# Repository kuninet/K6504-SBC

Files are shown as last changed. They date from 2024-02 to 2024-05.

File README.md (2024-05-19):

# K6504-SBC

## 概要

* R6504 CPU(6502 CPUの仲間)を使ったシングルボードコンピューターです。
  * アドレシングできる範囲は8kBです。
  * RAM4kB、ROM3kB UniversanMonitorを動かすのが目標です

## 回路図

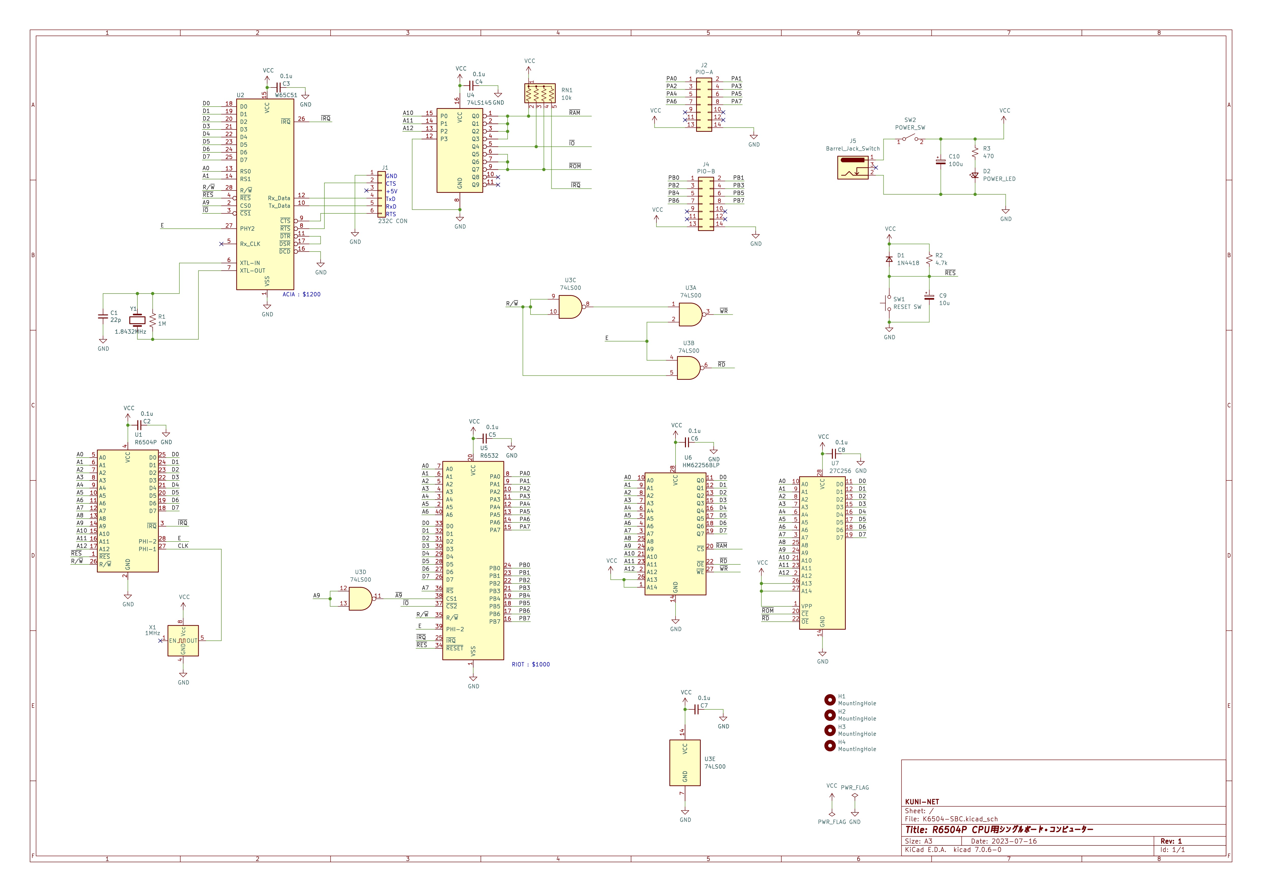
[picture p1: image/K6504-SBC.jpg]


## 基板製造データ

* プリント基板を製造するには、KiCAD/PCB フォルダに入っているzipファイルをお使いください。

## 部品表

[KiCAD/K6504-SBC.csv](KiCAD/K6504-SBC.csv)

## 注意点

* シリアルIC(6551)、RAM/IO/TIMER IC(6532)の割り込み信号線は、基板裏のソルダージャンパーをはんだで短絡すると有効になります。

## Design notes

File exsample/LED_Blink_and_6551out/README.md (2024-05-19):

# LEDチカチカ & W65C51経由シリアルへの出力テスト

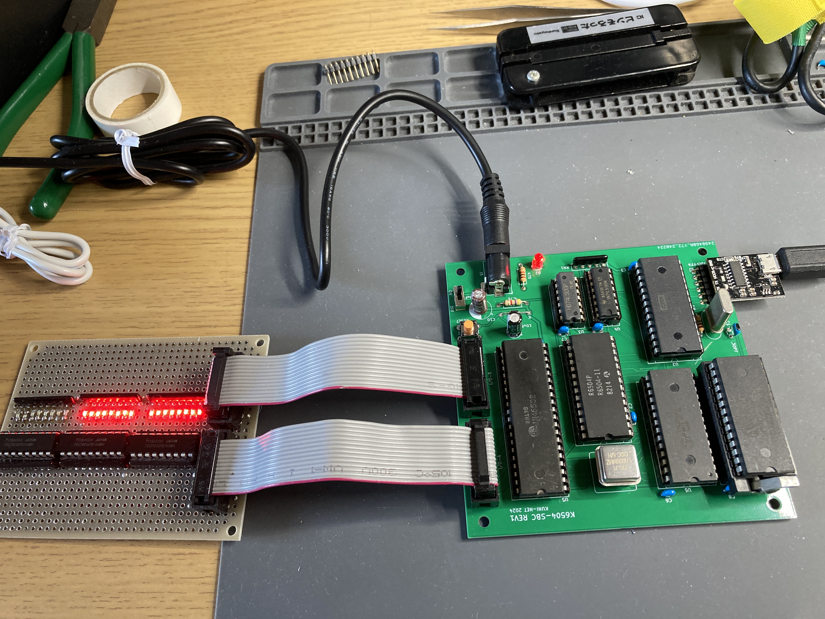
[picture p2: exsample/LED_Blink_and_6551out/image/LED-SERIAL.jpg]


## 概要

* K6504-SBCの単純な動作確認として使える、LEDチカチカ(1～255カウントアップ)と シリアルへの出力プログラムです。
  * ★ROMに焼いて使用するものです。

## アセンブリと使い方

### ソースからのビルド方法

* Linux等のUNIX環境で [The Macroassembler AS](http://john.ccac.rwth-aachen.de:8000/as/)が動くようにしてください。アセンブリに必要なツールです。
  * 基本的に `Downloadページ` > `latest build`のCソースを持ってきて、gccでmake & make installするだけです。
* Makefileが入ってますので、 `make` コマンドを実行すると `out-6502.hex` ができあがります。TL866 II PlusなどでROMに焼いてお使いください。
  * Universal MonitorのLコマンドでロードしたりして使いたい場合は、先頭アドレス ORGを `$0100` にするなど適宜変更してください。

```
$ make
```
* ビルドしてできたインテルHEXファイルは$1600からのデータとなってます。ROMに焼く際は 適宜ロード先を指定してください。
  * W27C512 : 1600 ⇒ F600 を指定
  * 27C256(UV-EPROM) : 1600 ⇒ 7600 を指定 

### 使い方

* K6504-SBCのI/O端子(14Pボックスヘッダ)経由でLED(8x2セット)を接続してください。
* シリアル端子にはFTDI準拠のUSBシリアル等を接続してください。
  * TeraTerm等の設定は9600bpsに設定してください。
* ROMに焼いた等プログラムをK6504-SBCに装着して電源ONすると、LEDがバイナリで1～255まで順次カウントアップします。また同じデータをシリアル端子にも出力します。(なんでもかんでもシリアルに出力するので文字化けするかも)

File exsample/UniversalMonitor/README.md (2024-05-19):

# Universal Monitor関係

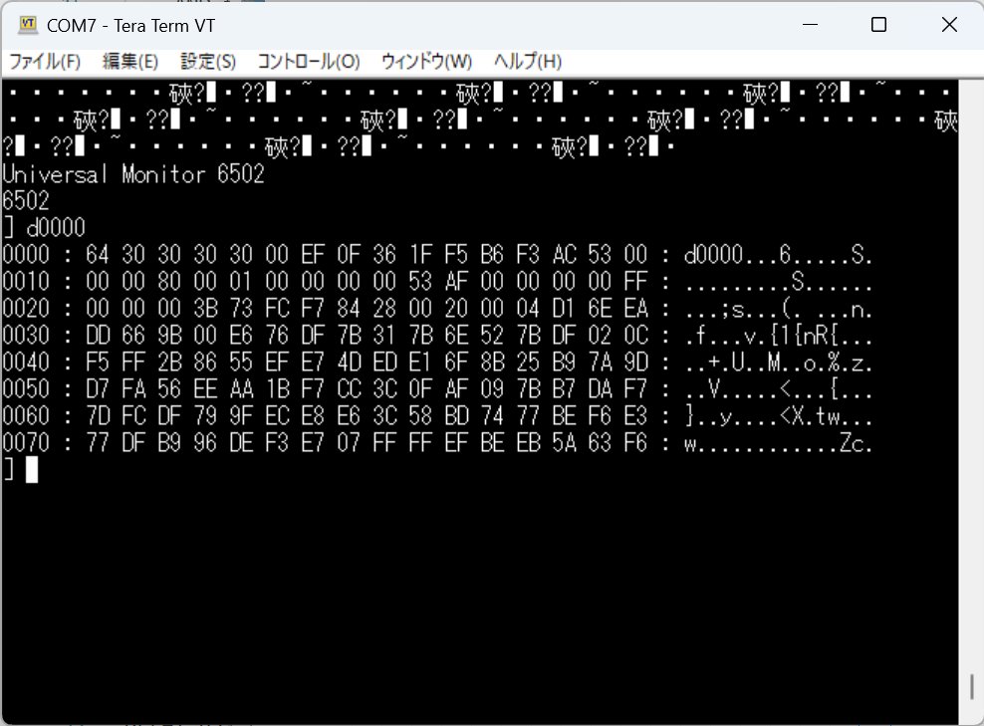
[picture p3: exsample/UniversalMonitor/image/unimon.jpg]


## 概要

* K6504-SBCで動くUniversal MonitorのROMイメージをビルドするために必要なファイルです。

## サンプルとして含まれるファイル

|ファイル名|説明|
|:--|:--|
|config.K6504-SBC|K6504-SBC用configファイル|
|dev_6551.asm|K6504-SBCのACIA(W65C51)対応コンソールドライバ|

## ビルドの注意

* Universal Monitorのソースを展開してでてくるなかの `6502` フォルダのソースを使ってください。
* `dev_6551.asm` をでコンソールドライバとして使ってください。(W65C51バグ対応版です。)
  * TeraTermで9600bpsで通信可能です。
* ACIA(W65C51)のアドレス等は `config.K6504-SBC` に書いてます。congih.incとしてお使いください。
* ビルドしてできたインテルHEXファイルは$1600からのデータとなってます。ROMに焼く際は 適宜ロード先を指定してください。
  * W27C512 : 1600 ⇒ F600 を指定
  * 27C256(UV-EPROM) : 1600 ⇒ 7600 を指定 

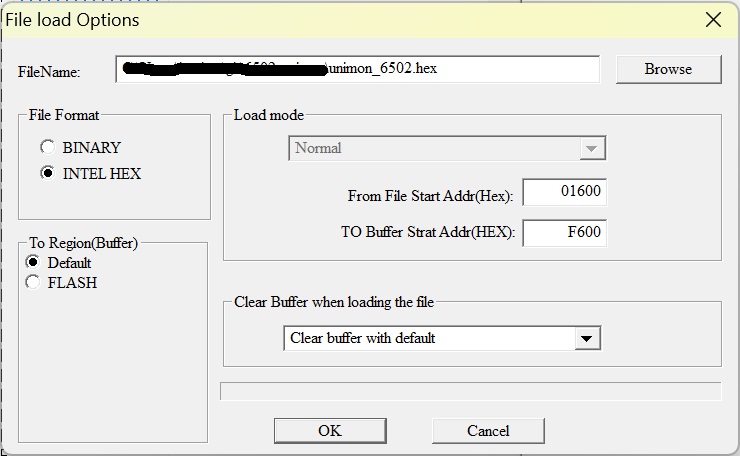
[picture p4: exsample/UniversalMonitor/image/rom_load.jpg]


## 参考

* UniversalMonitor > ビルド
  * https://electrelic.com/electrelic/node/1395

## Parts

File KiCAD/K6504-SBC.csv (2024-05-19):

Item | Qty | Reference(s) | Value | Comments | LibPart | Footprint | Datasheet | DNP | Sim.Device | Sim.Pins
1 | 1 | C1 | 22p～33p | セラミックコンデンサ | Device:C_Small | Capacitor_THT:C_Disc_D3.0mm_W1.6mm_P2.50mm | ~
2 | 7 | C2, C3, C4, C5, C6, C7, C8 | 0.1u | セラミックコンデンサ | Device:C_Small | Capacitor_THT:C_Disc_D3.0mm_W1.6mm_P2.50mm | ~
3 | 1 | C9 | 10u | 電解コンデンサ | Device:C_Polarized_Small | Capacitor_THT:CP_Radial_D5.0mm_P2.50mm | ~
4 | 1 | C10 | 100u | 電解コンデンサ | Device:C_Polarized_Small | Capacitor_THT:CP_Radial_D8.0mm_P2.50mm | ~
5 | 1 | D1 | 1N4418 | 小電力ダイオード | Device:D_Small | Diode_THT:D_DO-34_SOD68_P10.16mm_Horizontal | ~ |  | D | 1=K 2=A
6 | 1 | D2 | POWER_LED | 発光ダイオード | Device:LED_Small | LED_THT:LED_D3.0mm | ~
7 | 4 | H1, H2, H3, H4 | MountingHole | 基板穴(部品ではありません) | Mechanical:MountingHole | MountingHole:MountingHole_3.2mm_M3 | ~
8 | 1 | J1 | 232C CON | L型 1列 ピンヘッダ | Connector_Generic:Conn_01x06 | Connector_PinHeader_2.54mm:PinHeader_1x06_P2.54mm_Horizontal | ~
9 | 1 | J2 | PIO-A | ボックスヘッダ2列 x 7 | Connector_Generic:Conn_02x07_Odd_Even | Connector_PinHeader_2.54mm:PinHeader_2x07_P2.54mm_Vertical | ~
10 | 1 | J4 | PIO-B | ボックスヘッダ2列 x 7 | Connector_Generic:Conn_02x07_Odd_Even | Connector_PinHeader_2.54mm:PinHeader_2x07_P2.54mm_Vertical | ~
11 | 1 | J5 | MJ-179PH | 電源ジャック | Connector:Barrel_Jack_Switch | Connector_BarrelJack:BarrelJack_Horizontal | ~
12 | 1 | JP1 | ACIA JP | ソルダー(半田)ジャンパ ※ACIA割り込み許可用 | Jumper:SolderJumper_2_Open | Jumper:SolderJumper-2_P1.3mm_Open_RoundedPad1.0x1.5mm | ~
13 | 1 | JP2 | RIOT JP | ソルダー(半田)ジャンパ ※RIOT割り込み許可用 | Jumper:SolderJumper_2_Open | Jumper:SolderJumper-2_P1.3mm_Open_RoundedPad1.0x1.5mm | ~
14 | 1 | R1 | 1M | 抵抗器 | Device:R_US | Resistor_THT:R_Axial_DIN0204_L3.6mm_D1.6mm_P7.62mm_Horizontal | ~
15 | 1 | R2 | 4.7k | 抵抗器 | Device:R_Small_US | Resistor_THT:R_Axial_DIN0207_L6.3mm_D2.5mm_P10.16mm_Horizontal | ~
16 | 1 | R3 | 470～1k | 抵抗器(LED用) | Device:R_Small_US | Resistor_THT:R_Axial_DIN0207_L6.3mm_D2.5mm_P10.16mm_Horizontal | ~
17 | 1 | RN1 | 2.2k～10k | 集合抵抗器 | Device:R_Network04_US | Resistor_THT:R_Array_SIP5 | http://www.vishay.com/docs/31509/csc.pdf
18 | 1 | SW1 | RESET SW | タクトスイッチ | Switch:SW_Push | Button_Switch_THT:SW_PUSH_6mm_H4.3mm | ~
19 | 1 | SW2 | POWER_SW | 基板用スライドスイッチ | Switch:SW_SPST | Connector_PinHeader_2.54mm:PinHeader_1x03_P2.54mm_Vertical | ~
20 | 1 | U1 | R6504P | R6504 CPU | R65xx:R6504P | Package_DIP:DIP-28_W15.24mm_Socket
21 | 1 | U2 | W65C51 | 6551 シリアルIC | 6522-51:W65C51 | Package_DIP:DIP-28_W15.24mm_Socket | http://www.ti.com/lit/ds/symlink/sn74ls139a.pdf
22 | 1 | U3 | 74LS00 | ロジックIC | 74xx:74LS00 | Package_DIP:DIP-14_W7.62mm_Socket | http://www.ti.com/lit/gpn/sn74ls00
23 | 1 | U4 | 74LS145 | ロジックIC | 74xx:74LS145 | Package_DIP:DIP-16_W7.62mm_Socket | http://www.ti.com/lit/gpn/sn74LS145
24 | 1 | U5 | R6532 | 6532 RAM/IO/TIMER RIOT | R6532:R6532 | Package_DIP:DIP-40_W15.24mm_Socket
25 | 1 | U6 | HM62256BLP | 256kbit SRAM | Memory_RAM:HM62256BLP | Package_DIP:DIP-28_W15.24mm_Socket | https://web.mit.edu/6.115/www/document/62256.pdf
26 | 1 | U7 | 27C256 | 256kbit EPROM | Memory_EPROM:27C256 | Package_DIP:DIP-28_W15.24mm_Socket | http://ww1.microchip.com/downloads/en/DeviceDoc/doc0014.pdf
27 | 1 | X1 | 1MHz | 水晶発振器(正方形) | Oscillator:CXO_DIP8 | Oscillator:Oscillator_DIP-8 | http://cdn-reichelt.de/documents/datenblatt/B400/OSZI.pdf
28 | 1 | Y1 | 1.8432MHz | 水晶振動子 | Device:Crystal | Crystal:Crystal_HC49-U_Vertical | ~

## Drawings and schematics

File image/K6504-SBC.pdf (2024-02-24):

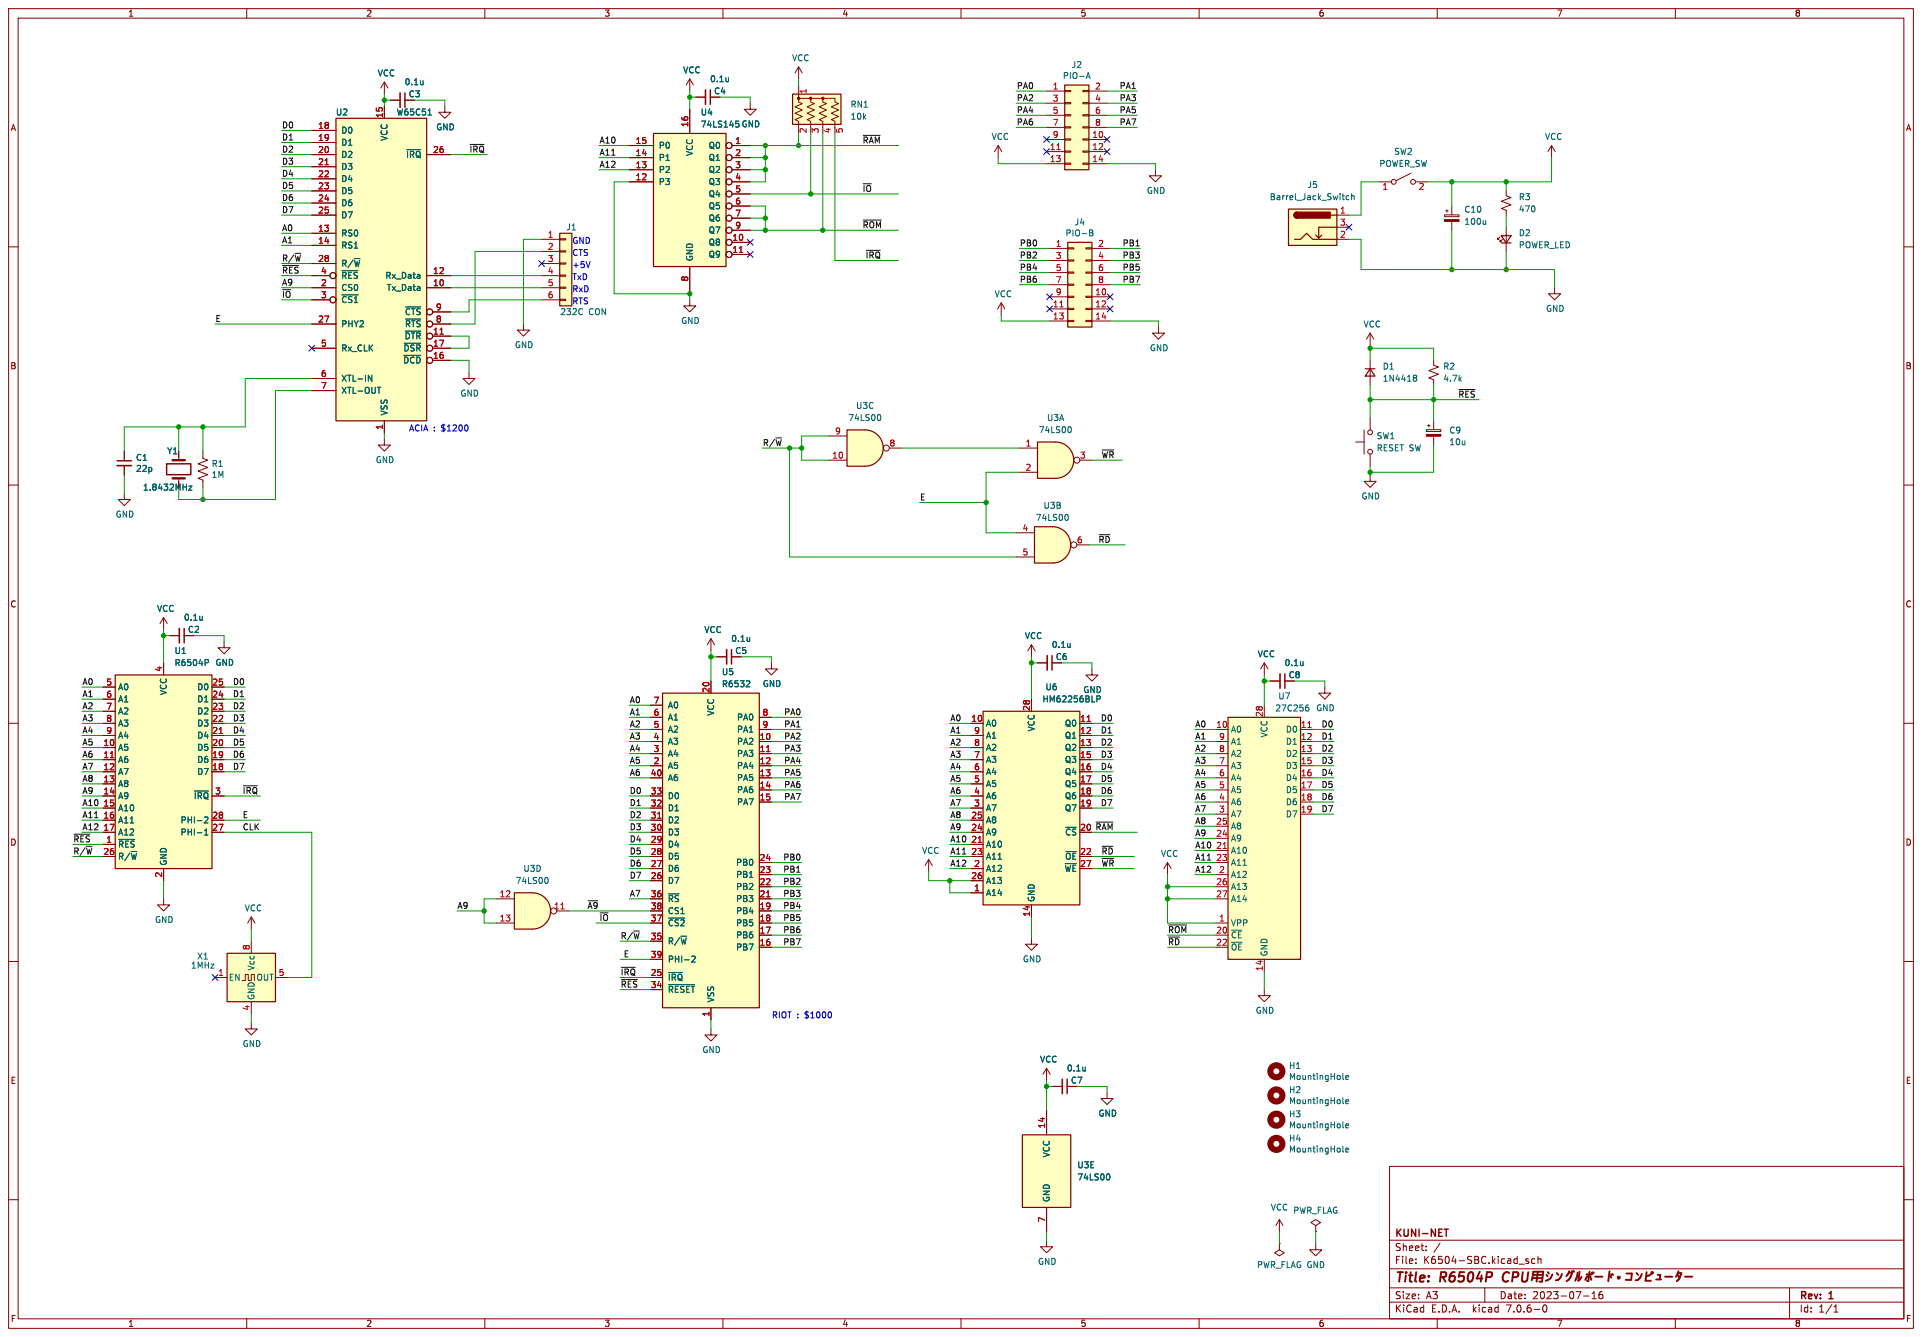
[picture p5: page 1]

1 PA2 10 PA3 11 PA4 12 PA5 13 PA6 14 PA7 15 PB7 16 PB6 17 PB5 18 PB4 19 A5 2 VCC 20 PB3 21 PB2 22 PB1 23 PB0 24 ~{IRQ} 25 D7 26 D6 27 D5 28 D4 29 A4 3 D3 30 D2 31 D1 32 D0 33 ~{RESET} 34 R/~{W} 35 ~{RS} 36 ~{CS2} 37 CS1 38 PHI-2 39 A3 4 A6 40 A2 5 A1 6 A0 7 PA0 8 PA1 9 VCC

4 ~{RES} 1 A5 10 A6 11 A7 12 A8 13 A9 14 A10 15 A11 16 A12 17 D7 18 D6 19 D5 20 D4 21 D3 22 D2 23 D1 24 D0 25 R/~{W} 26 PHI-1 27 PHI-2 28 ~{IRQ}3 A0 5 A1 6 A2 7 A3 8 A4 9 U1 R6504P GND

4 ~{RES} 1 A5 10 A6 11 A7 12 A8 13 A9 14 A10 15 A11 16 A12 17 D7 18 D6 19 D5 20 D4 21 D3 22 D2 23 D1 24 D0 25 R/~{W} 26 PHI-1 27 PHI-2 28 ~{IRQ}3 A0 5 A1 6 A2 7 A3 8 A4 9 U6 HM62256BLP GND 14 VCC 28 A14 1 A0 10 Q0 11 Q1 12 Q2 13 Q3 15 Q4 16 Q5 17 Q6 18 Q7 19 A12 2 ~{CS} 20 A10 21 ~{OE} 22 A11 23 A9 24 A8 25 A13 26 ~{WE} 27 A7 3 A6 4 A5 5 A4 6 A3 7 A2 8 A1 9 C7

1 PA2 10 PA3 11 PA4 12 PA5 13 PA6 14 PA7 15 PB7 16 PB6 17 PB5 18 PB4 19 A5 2 VCC 20 PB3 21 PB2 22 PB1 23 PB0 24 ~{IRQ} 25 D7 26 D6 27 D5 28 D4 29 A4 3 D3 30 D2 31 D1 32 D0 33 ~{RESET} 34 R/~{W} 35 ~{RS} 36 ~{CS2} 37 CS1 38 PHI-2 39 A3 4 A6 40 A2 5 A1 6 A0 7 PA0 8 PA1 9 U5 R6532

Id: 1/1 Title: R6504P þÿCPUu(0·0ó0°0ë0Ü0ü0É0û0³0ó0Ô0å0ü0¿0ü

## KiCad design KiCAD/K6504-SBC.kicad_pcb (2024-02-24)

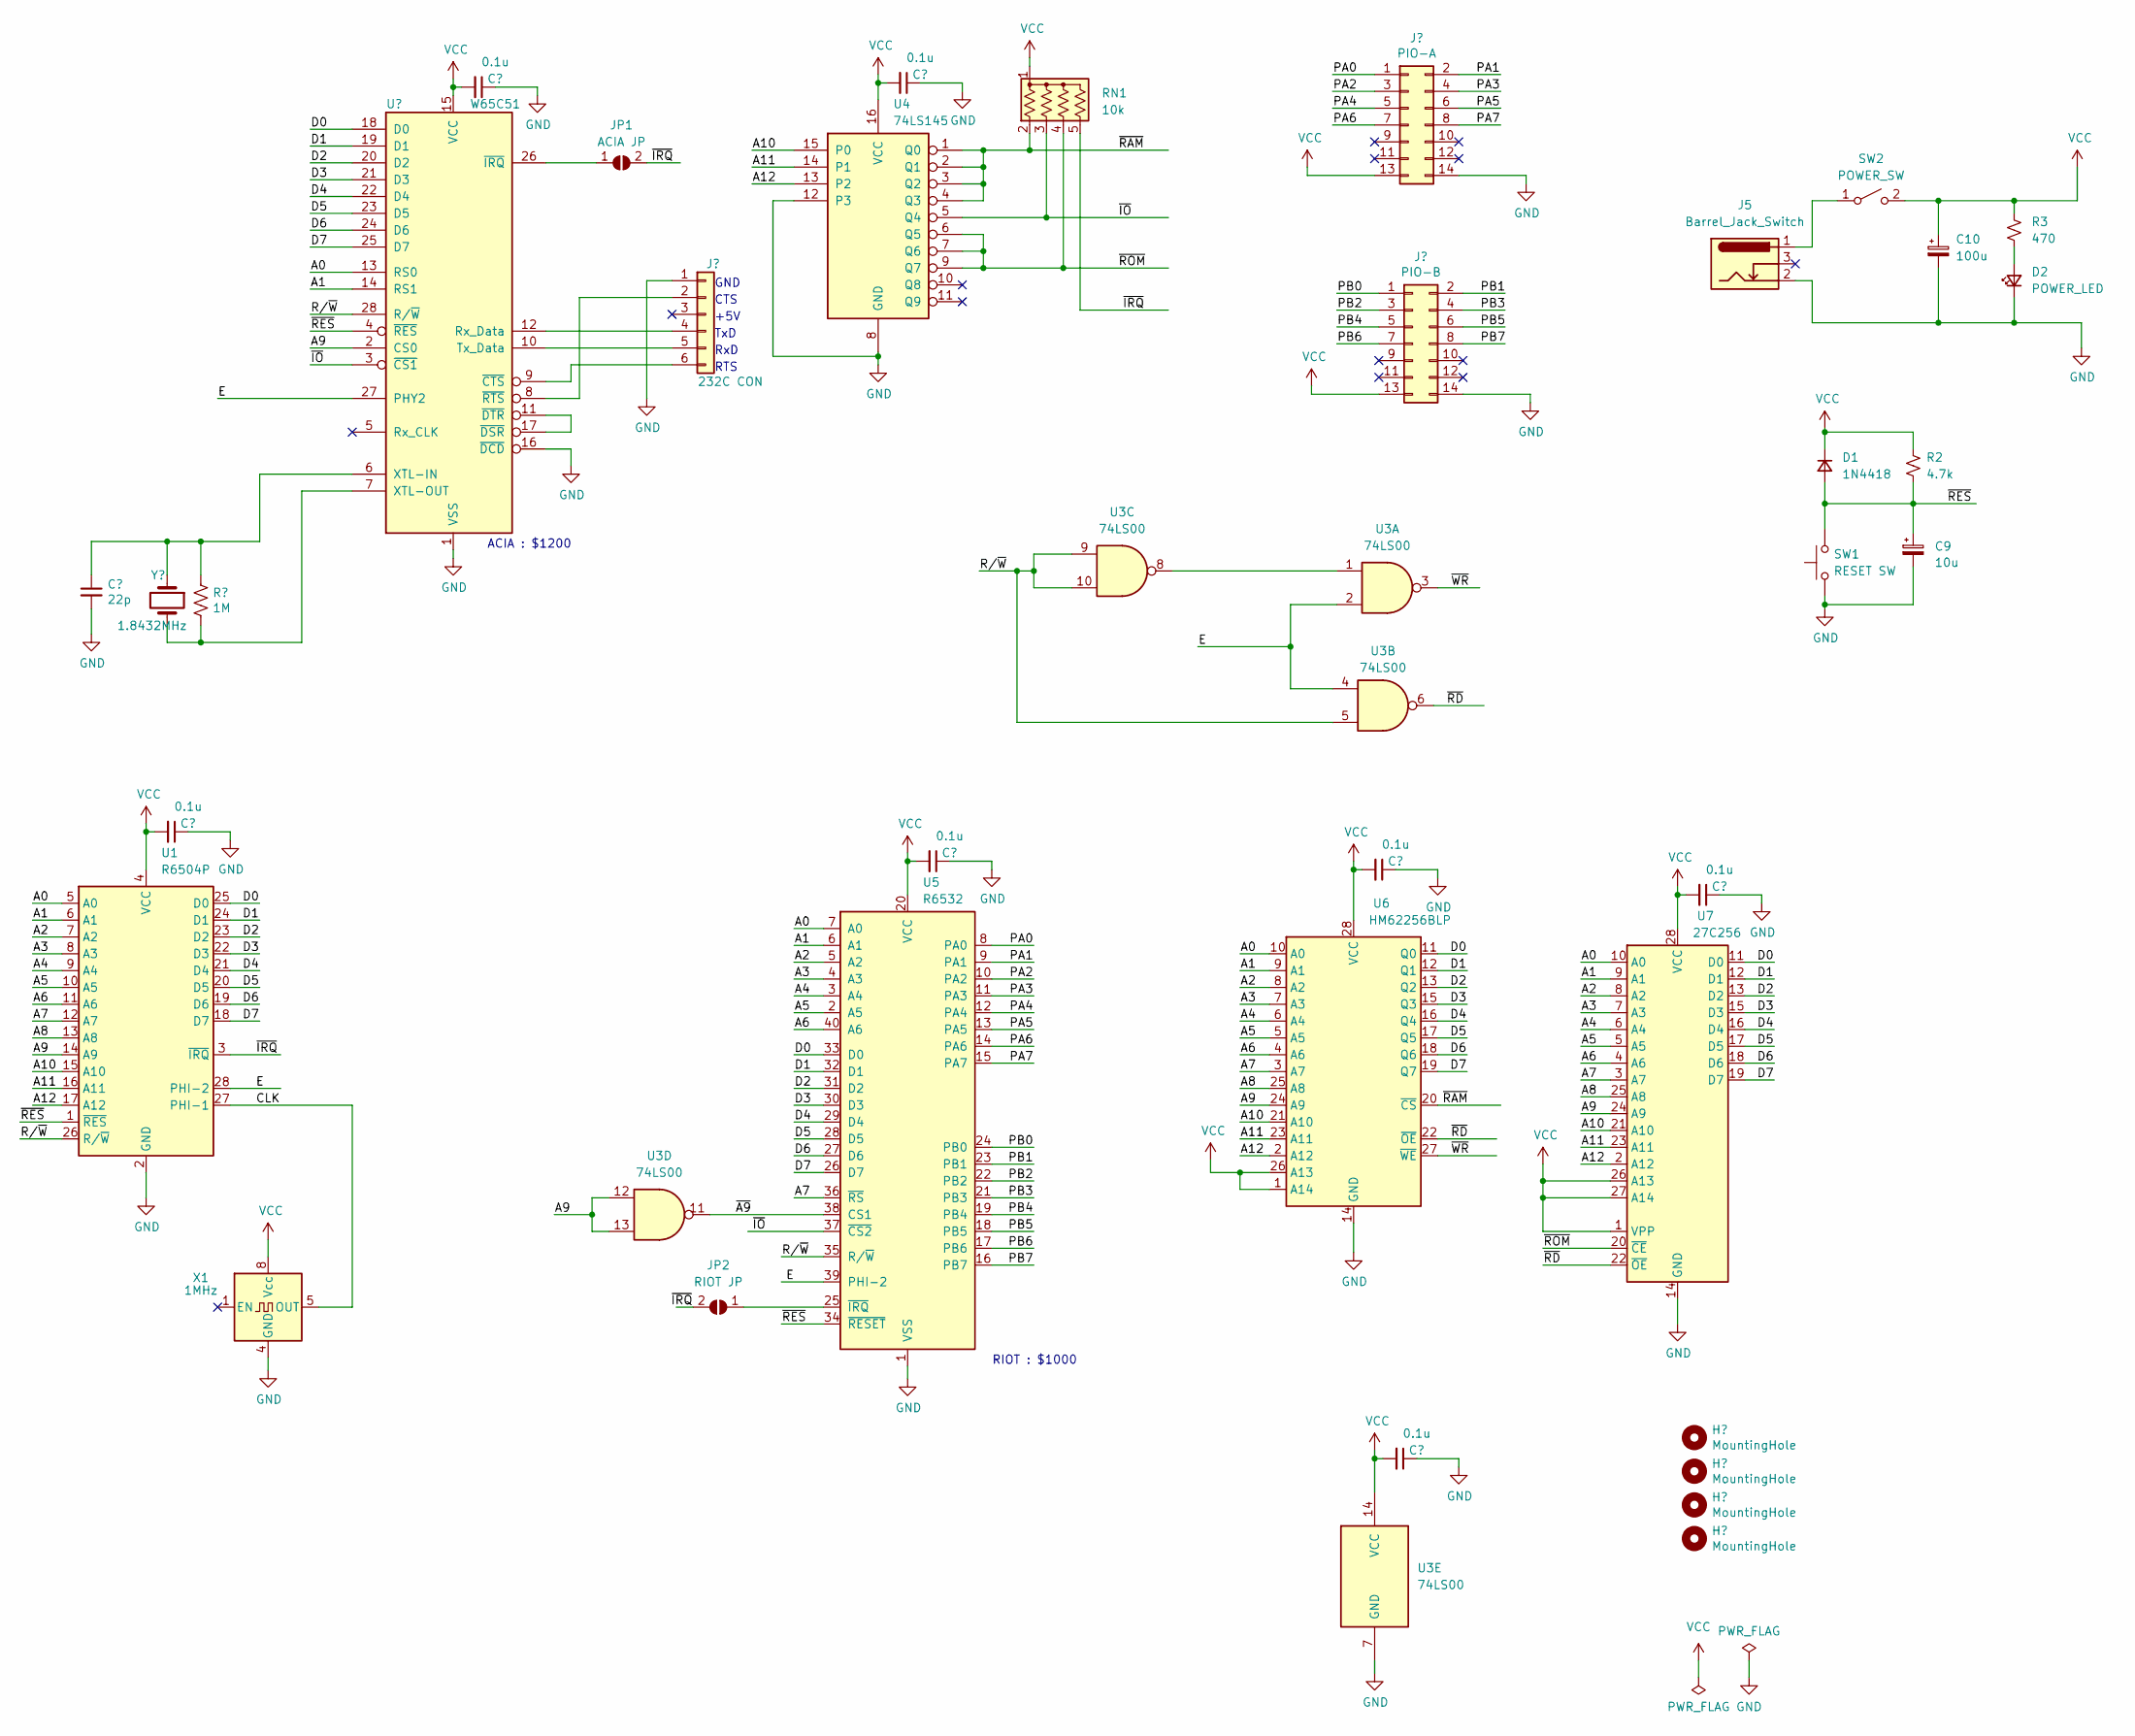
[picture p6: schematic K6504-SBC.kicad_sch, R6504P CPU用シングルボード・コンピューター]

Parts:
C1: 22p; C_Disc_D3.0mm_W1.6mm_P2.50mm
C2, C3, C4, C5, C6, C7, C8: 0.1u; C_Disc_D3.0mm_W1.6mm_P2.50mm
C9: 10u; CP_Radial_D5.0mm_P2.50mm
C10: 100u; CP_Radial_D8.0mm_P2.50mm
D1: 1N4418; D_DO-34_SOD68_P10.16mm_Horizontal
D2: POWER_LED; LED_D3.0mm
H1, H2, H3, H4: MountingHole; MountingHole_3.2mm_M3
J1: 232C CON; PinHeader_1x06_P2.54mm_Horizontal
J2: PIO-A; PinHeader_2x07_P2.54mm_Vertical
J4: PIO-B; PinHeader_2x07_P2.54mm_Vertical
J5: Barrel_Jack_Switch; BarrelJack_Horizontal
JP1: ACIA JP; SolderJumper-2_P1.3mm_Open_RoundedPad1.0x1.5mm
JP2: RIOT JP; SolderJumper-2_P1.3mm_Open_RoundedPad1.0x1.5mm
R1: 1M; R_Axial_DIN0204_L3.6mm_D1.6mm_P7.62mm_Horizontal
R2: 4.7k; R_Axial_DIN0207_L6.3mm_D2.5mm_P10.16mm_Horizontal
R3: 470; R_Axial_DIN0207_L6.3mm_D2.5mm_P10.16mm_Horizontal
RN1: 10k; R_Array_SIP5
SW1: RESET SW; SW_PUSH_6mm_H4.3mm
SW2: POWER_SW; PinHeader_1x03_P2.54mm_Vertical
U1: R6504P; DIP-28_W15.24mm_Socket
U2: W65C51; DIP-28_W15.24mm_Socket
U3: 74LS00; DIP-14_W7.62mm_Socket
U4: 74LS145; DIP-16_W7.62mm_Socket
U5: R6532; DIP-40_W15.24mm_Socket
U6: HM62256BLP; DIP-28_W15.24mm_Socket
U7: 27C256; DIP-28_W15.24mm_Socket
X1: 1MHz; Oscillator_DIP-8
Y1: 1.8432MHz; Crystal_HC49-U_Vertical

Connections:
/A0: U1.5 (A0), U2.13 (RS0), U5.7 (A0), U6.10 (A0), U7.10 (A0)
/A1: U1.6 (A1), U2.14 (RS1), U5.6 (A1), U6.9 (A1), U7.9 (A1)
/A2: U1.7 (A2), U5.5 (A2), U6.8 (A2), U7.8 (A2)
/A3: U1.8 (A3), U5.4 (A3), U6.7 (A3), U7.7 (A3)
/A4: U1.9 (A4), U5.3 (A4), U6.6 (A4), U7.6 (A4)
/A5: U1.10 (A5), U5.2 (A5), U6.5 (A5), U7.5 (A5)
/A6: U1.11 (A6), U5.40 (A6), U6.4 (A6), U7.4 (A6)
/A7: U1.12 (A7), U5.36 (~RS), U6.3 (A7), U7.3 (A7)
/A8: U1.13 (A8), U6.25 (A8), U7.25 (A8)
/A9: U1.14 (A9), U2.2 (CS0), U3.12, U3.13, U6.24 (A9), U7.24 (A9)
/A10: U1.15 (A10), U4.15 (P0), U6.21 (A10), U7.21 (A10)
/A11: U1.16 (A11), U4.14 (P1), U6.23 (A11), U7.23 (A11)
/A12: U1.17 (A12), U4.13 (P2), U6.2 (A12), U7.2 (A12)
/CLK: U1.27 (PHI-1), X1.5 (OUT)
/D0: U1.25 (D0), U2.18 (D0), U5.33 (D0), U6.11 (Q0), U7.11 (D0)
/D1: U1.24 (D1), U2.19 (D1), U5.32 (D1), U6.12 (Q1), U7.12 (D1)
/D2: U1.23 (D2), U2.20 (D2), U5.31 (D2), U6.13 (Q2), U7.13 (D2)
/D3: U1.22 (D3), U2.21 (D3), U5.30 (D3), U6.15 (Q3), U7.15 (D3)
/D4: U1.21 (D4), U2.22 (D4), U5.29 (D4), U6.16 (Q4), U7.16 (D4)
/D5: U1.20 (D5), U2.23 (D5), U5.28 (D5), U6.17 (Q5), U7.17 (D5)
/D6: U1.19 (D6), U2.24 (D6), U5.27 (D6), U6.18 (Q6), U7.18 (D6)
/D7: U1.18 (D7), U2.25 (D7), U5.26 (D7), U6.19 (Q7), U7.19 (D7)
/E: U1.28 (PHI-2), U2.27 (PHY2), U3.2, U3.4, U5.39 (PHI-2)
/PA0: J2.1, U5.8 (PA0)
/PA1: J2.2, U5.9 (PA1)
/PA2: J2.3, U5.10 (PA2)
/PA3: J2.4, U5.11 (PA3)
/PA4: J2.5, U5.12 (PA4)
/PA5: J2.6, U5.13 (PA5)
/PA6: J2.7, U5.14 (PA6)
/PA7: J2.8, U5.15 (PA7)
/PB0: J4.1, U5.24 (PB0)
/PB1: J4.2, U5.23 (PB1)
/PB2: J4.3, U5.22 (PB2)
/PB3: J4.4, U5.21 (PB3)
/PB4: J4.5, U5.19 (PB4)
/PB5: J4.6, U5.18 (PB5)
/PB6: J4.7, U5.17 (PB6)
/PB7: J4.8, U5.16 (PB7)
/R/~W: U1.26 (R/~W), U2.28 (R/~W), U3.5, U3.9, U3.10, U5.35 (R/~W)
/~A9: U3.11, U5.38 (CS1)
/~IO: RN1.3 (R2), U2.3 (~CS1), U4.5 (Q4), U5.37 (~CS2)
/~IRQ: JP1.2 (B), JP2.2 (B), RN1.5 (R4), U1.3 (~IRQ)
/~RAM: RN1.2 (R1), U4.1 (Q0), U4.2 (Q1), U4.3 (Q2), U4.4 (Q3), U6.20 (~CS)
/~RD: U3.6, U6.22 (~OE), U7.22 (~OE)
/~RES: C9.1, D1.2 (A), R2.2, SW1.2, U1.1 (~RES), U2.4 (~RES), U5.34 (~RESET)
/~ROM: RN1.4 (R3), U4.6 (Q5), U4.7 (Q6), U4.9 (Q7), U7.20 (~CE)
/~WR: U3.3, U6.27 (~WE)
GND: C1.2, C2.1, C3.1, C4.1, C5.1, C6.1, C7.1, C8.1, C9.2, C10.2, D2.1 (K), J1.1, J2.14, J4.14, J5.2, SW1.1, U1.2 (GND), U2.1 (VSS), U2.16 (~DCD), U3.7 (GND), U4.8 (GND), U4.12 (P3), U5.1 (VSS), U6.14 (GND), U7.14 (GND), X1.4 (GND)
unnamed: D2.2 (A), R3.2
unnamed: J1.2, U2.8 (~RTS)
unnamed: J1.4, U2.12 (Rx_Data)
unnamed: J1.5, U2.10 (Tx_Data)
unnamed: J1.6, U2.9 (~CTS)
unnamed: JP1.1 (A), U2.26 (~IRQ)
unnamed: JP2.1 (A), U5.25 (~IRQ)
unnamed: J5.1, SW2.1 (A)
unnamed: C1.1, R1.1, U2.6 (XTL-IN), Y1.1
unnamed: R1.2, U2.7 (XTL-OUT), Y1.2
unnamed: U2.11 (~DTR), U2.17 (~DSR)
unnamed: U3.1, U3.8
VCC: C2.2, C3.2, C4.2, C5.2, C6.2, C7.2, C8.2, C10.1, D1.1 (K), J2.13, J4.13, R2.1, R3.1, RN1.1 (common), SW2.2 (B), U1.4 (VCC), U2.15 (VCC), U3.14 (VCC), U4.16 (VCC), U5.20 (VCC), U6.1 (A14), U6.26 (A13), U6.28 (VCC), U7.1 (VPP), U7.26 (A13), U7.27 (A14), U7.28 (VCC), X1.8 (Vcc)

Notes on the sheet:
GND
RIOT : $1000
ACIA : $1200
RTS
RxD
+5V
CTS
TxD

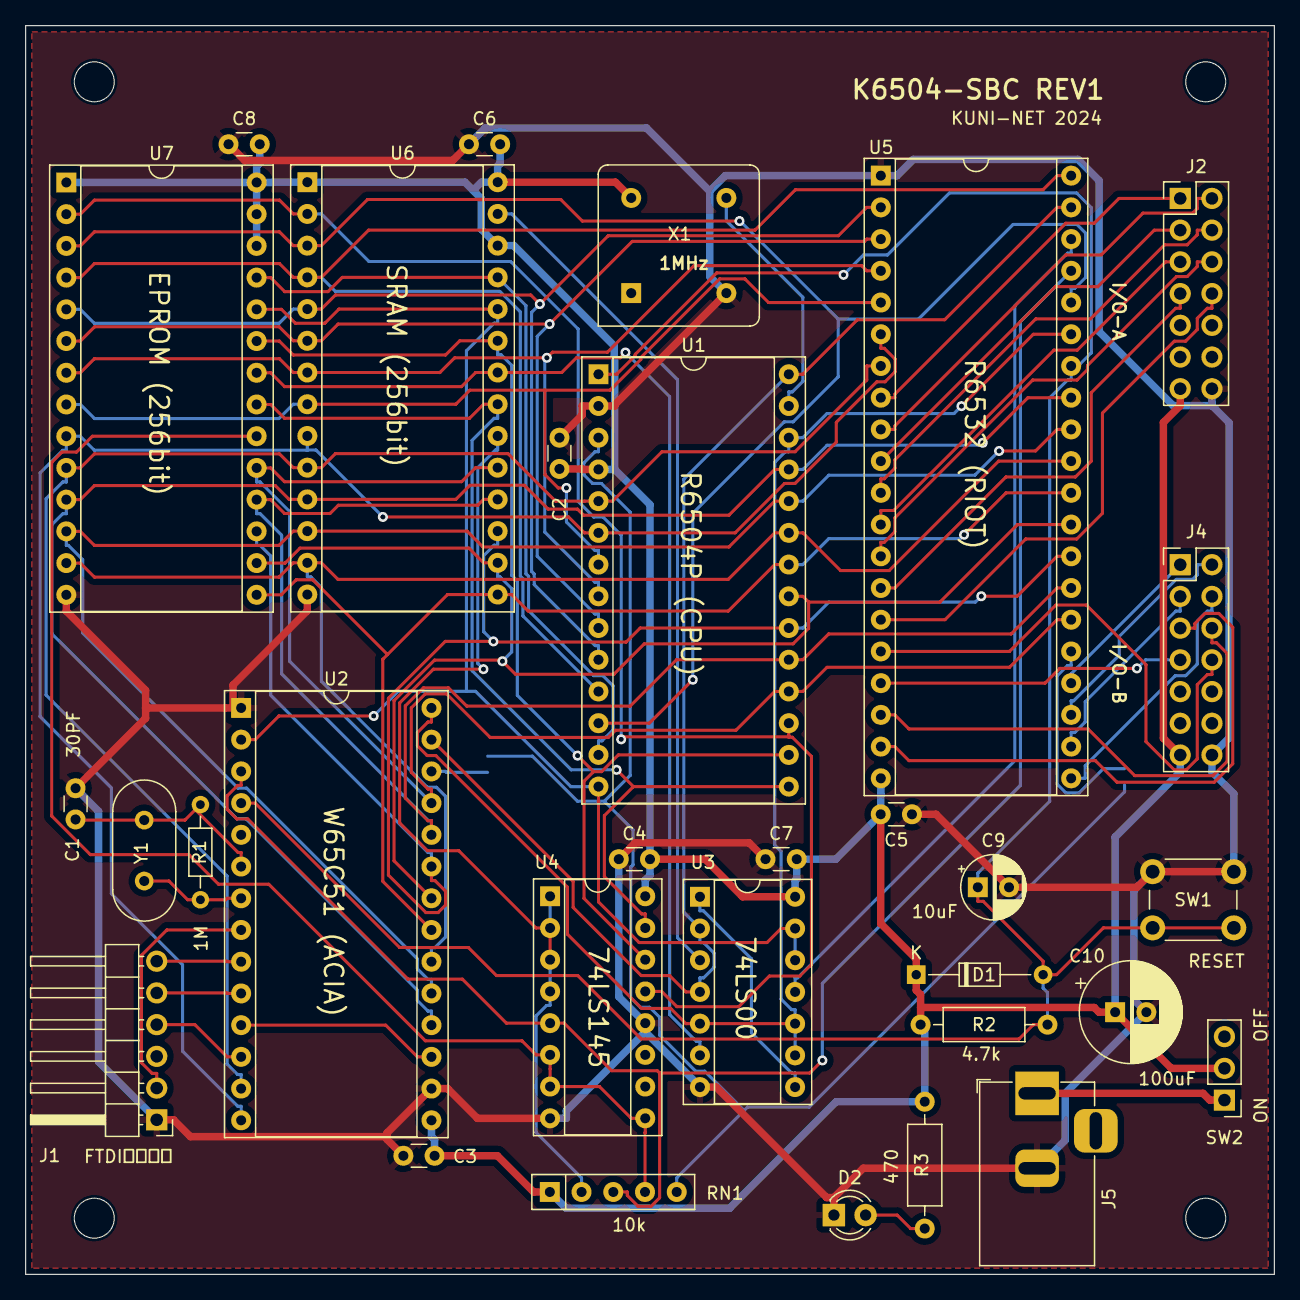
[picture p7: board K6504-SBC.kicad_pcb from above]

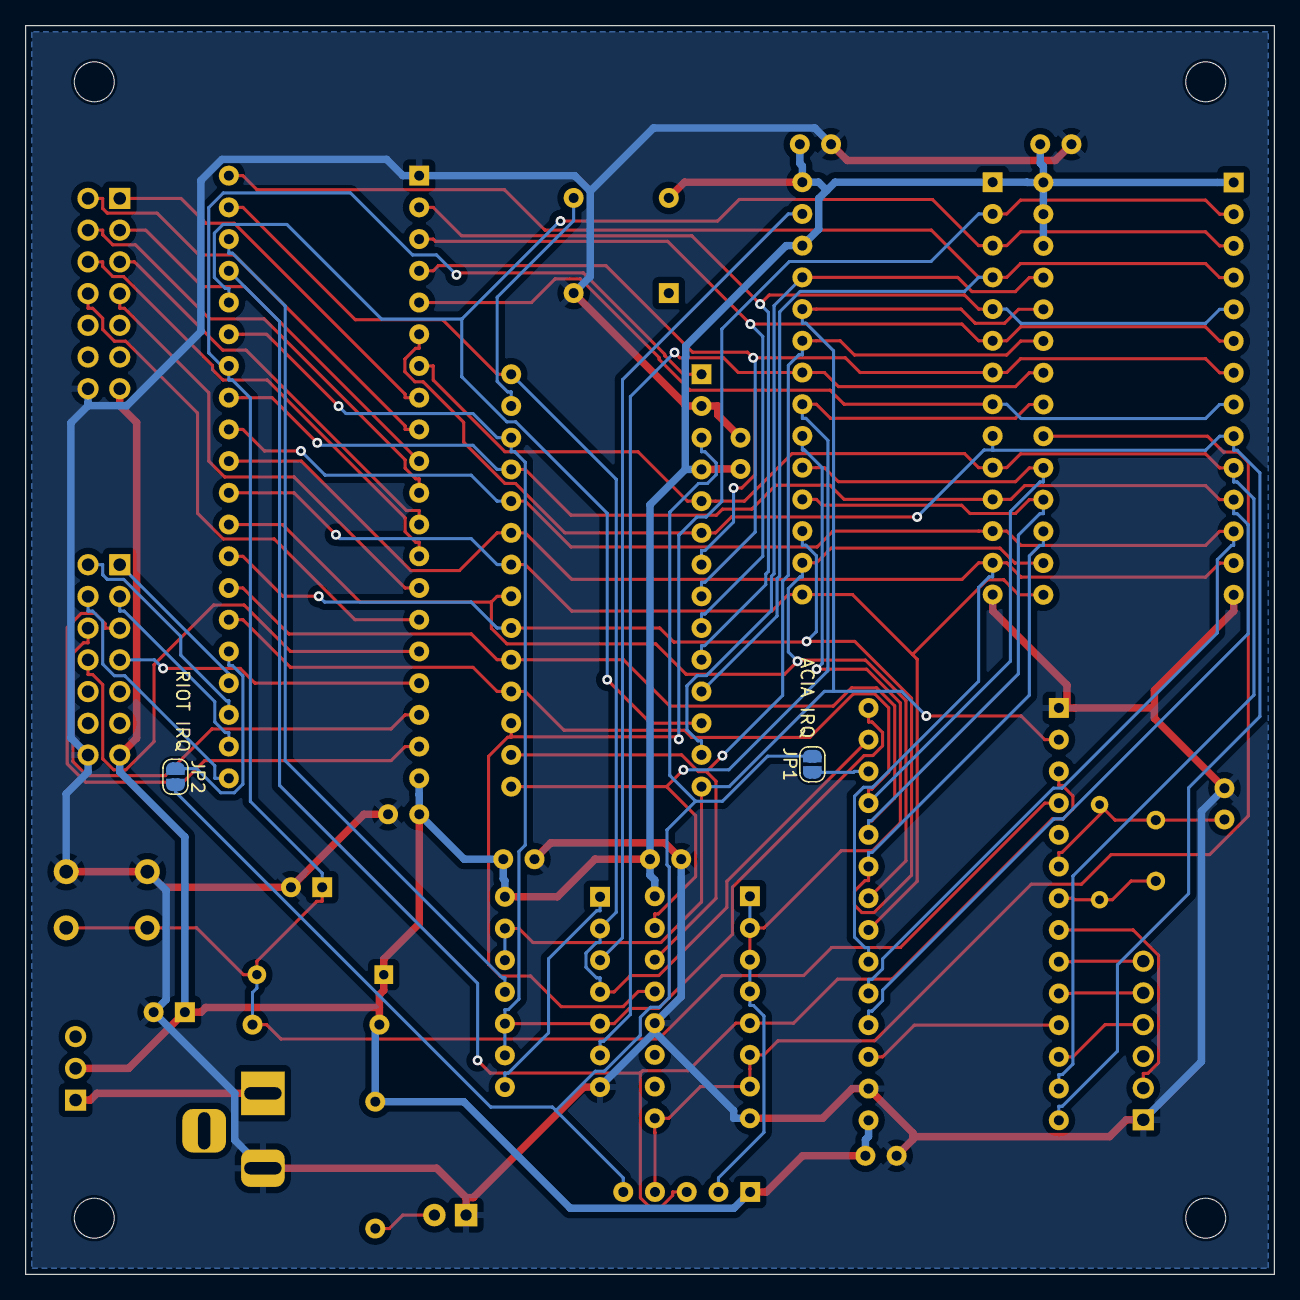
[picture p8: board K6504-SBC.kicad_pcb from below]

Board: 2 copper layers, 100.0 x 100.0 mm, 37 parts (2 on the bottom side), 62 nets.

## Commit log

2023-10-01 KiCAD7で回路図作成、回路図イメージファイル添付
    [K6504-SBC.kicad_pcb, K6504-SBC.kicad_sch]
2024-02-23 メモリーマップ見直し & 回路図見直し
    [K6504-SBC.kicad_sch]
2024-02-23 回路図見直し
    [K6504-SBC.kicad_sch]
2024-02-24 回路図 : R6404シンボル間違い修正、IRQプルアップ忘れ修正
    [K6504-SBC.kicad_sch]
2024-02-24 部品との関連付け追加
    [K6504-SBC.kicad_sch]
2024-02-24 コンデンサ定数修正、回路図イメージ更新
    [K6504-SBC.kicad_sch]
2024-02-24 基板サイズ見直し、ガーバーデータ再出力
    [K6504-SBC.dsn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]
2024-02-24 部品表追加KiCAD\K6504-SBC.csv
    [K6504-SBC.csv]
2024-05-19 動作確認等のサンプルソース追加
2024-05-19 サンプル ソース間違い修正
